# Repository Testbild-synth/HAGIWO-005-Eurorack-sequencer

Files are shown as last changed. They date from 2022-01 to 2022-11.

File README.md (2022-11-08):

# HAGIWO 005 Eurorack Generative Sequencer Module
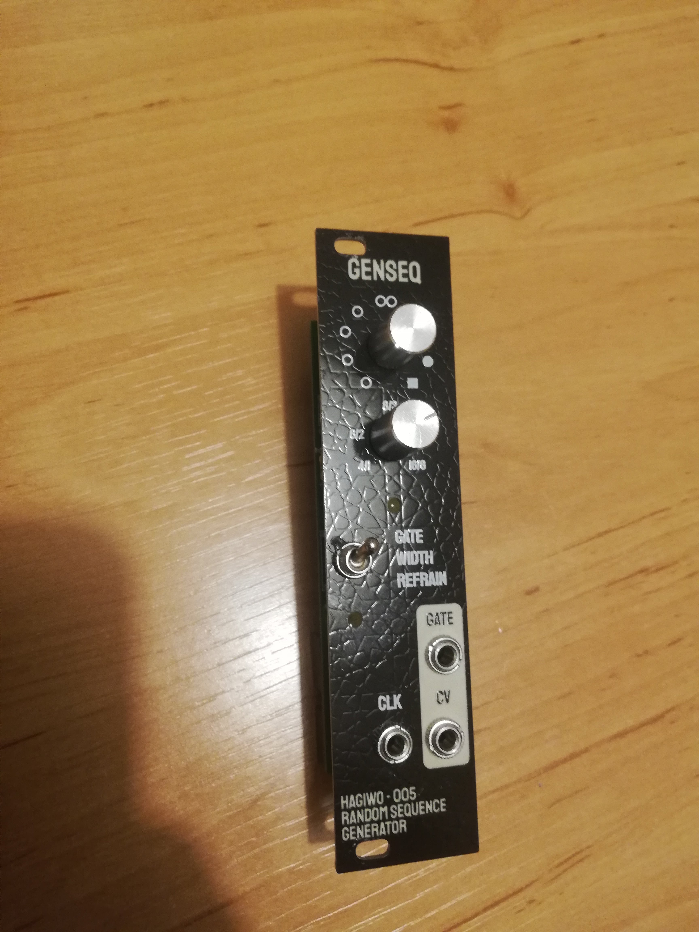
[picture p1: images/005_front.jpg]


Through hole PCB version of the [HAGIWO 005 Generative Sequencer](https://www.youtube.com/watch?v=S4yxVxi9Iak) Eurorack module.
The module is a very simple Arduino-based CV and gate generator that gives random sequences similar to a music things modular turing machine.
Parameters can be set to change different parameters of the sequence.

## Hardware and PCB
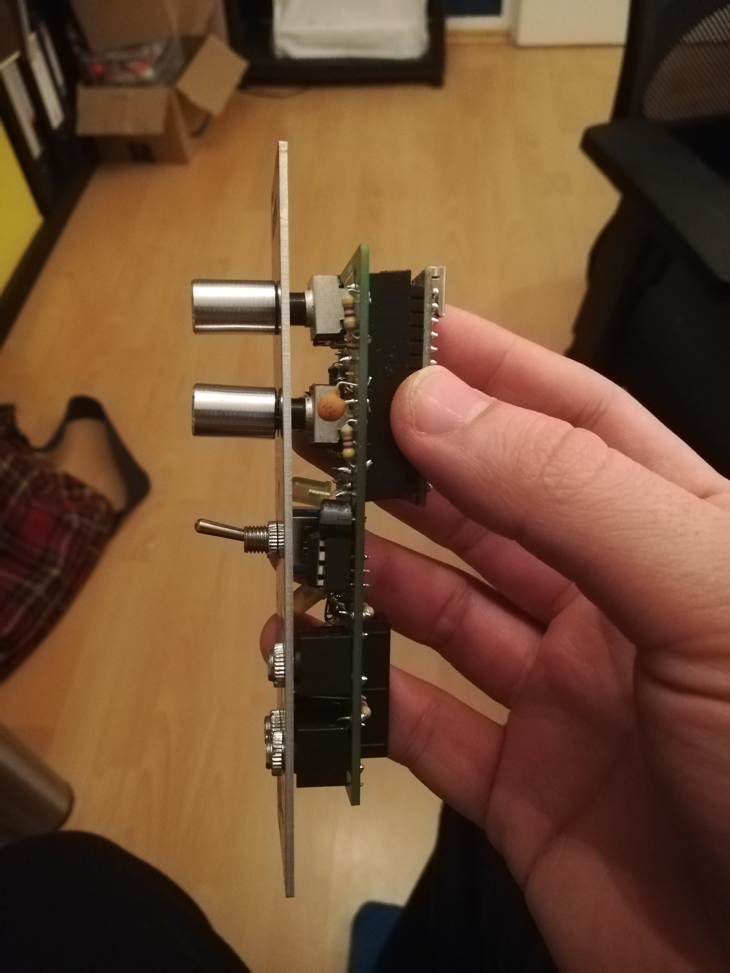
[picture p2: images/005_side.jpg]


You can find the schematic and BOM in the root folder. For the PCBs, the module has one circuit PCB and one panel PCB. You can order them on any common PCB manufacturing service, I used JLCPCB. Standard settings should be fine.

I have uploaded the panel kicad and inkscape files if you want to change fonts etc. (I use the great [svg2shenzen](https://github.com/badgeek/svg2shenzhen) inkscape extension to do my panels.

you should probably make the led resistors (the 330 ohm ones) something higher like 1k, the leds on mine are very bright

As with some of my other modules, this pcb has a selector which allows you to choose if it runs off the 12V or 5V power bus (as some people want 5V but others don't have it in their racks). simply solder the bridge from V_sel to either side or put in a jumper to choose.    

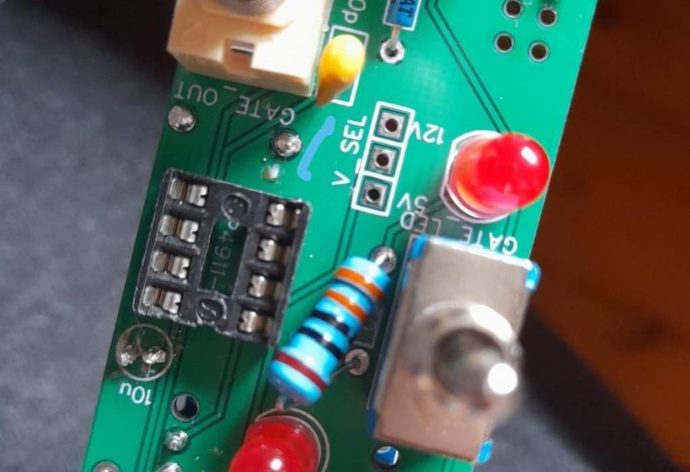
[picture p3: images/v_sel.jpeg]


# TODO:
- code cleanup (it works but could be prettier)

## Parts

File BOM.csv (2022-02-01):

ID | Name | Designator | Type | Quantity
1 | 10u | C1 | Electrolytic capacitor through hole | 1
2 | 220p | C2,C3 | ceramic capacitor through hole | 2
3 | BAT43 | D1,D2 | Schottky diode through hole | 2
6 | CLOCK_IN, GATE_OUT, V_OUT | J3,J4,J11 | Thonkikonn Jack | 3
10 | GATE_LED, OUT_ELD | LED1,LED2 | LED 5mm | 2
12 | 100k | MAIN,SUB | R9k potentiometer | 2
13 | PWR | P1 | Eurorack Power header | 1
14 | 470 | R1,R2,R3,R4,R11 | Resistor through hole | 5
15 | 330 | R5,R6 | Resistor through hole | 2
16 | ARDUINO_NANO | U1 | Arduino nano v3 | 1
17 | MCP4911-EP | U2 | MCP4911 DIP8 DAC | 1
18 | Switch | U3 | MS103 SPDT on/off/on switch | 1

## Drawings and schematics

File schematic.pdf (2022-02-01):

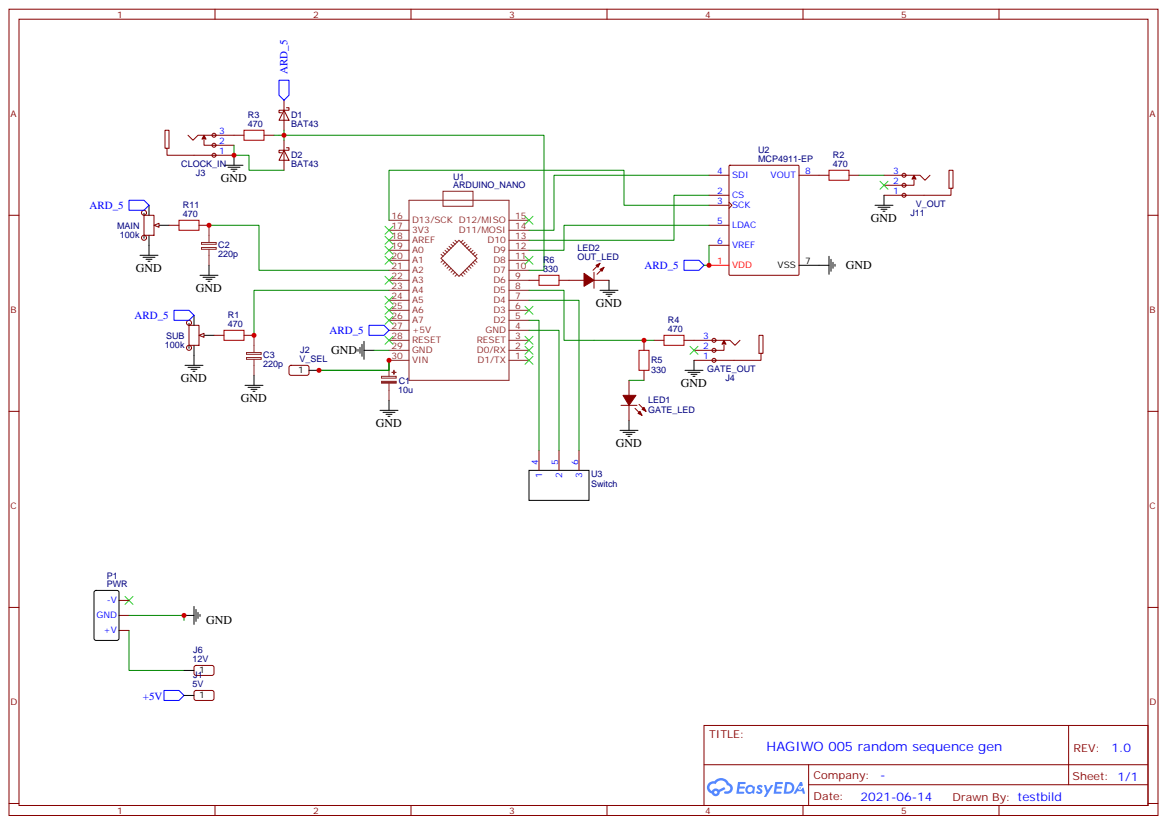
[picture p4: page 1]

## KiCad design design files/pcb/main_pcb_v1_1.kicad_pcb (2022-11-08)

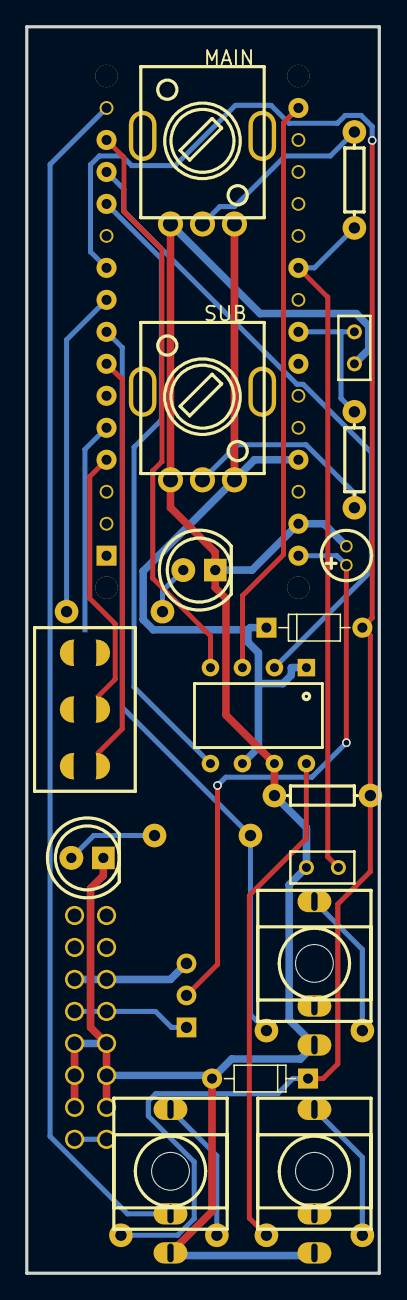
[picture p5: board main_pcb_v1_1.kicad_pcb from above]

Board: 2 copper layers, 28.0 x 99.0 mm, 25 parts (0 on the bottom side), 27 nets.

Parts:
5V: HDR-F-2.54_1x3; HDR-F-2.54_1X3
C1: 10u; CAP-D4.0×F1.5
C2, C3: 220p; RAD-0.1
D1, D2: BAT43; D_DO-35_SOD27_P7.62MM_HORIZONTAL
J3: CLOCK_IN; THONKICONN_1
J4: GATE_OUT; THONKICONN_1
J11: V_OUT; THONKICONN_1
LED1: GATE_LED; LED 5MM
LED2: OUT_LED; LED 5MM
MAIN: 100k; R09-5KΩ
P18: PWR; HDR-IDC-2.54-2X8P
R1, R3, R11: 470; R_AXIAL-0.3
R2, R4: 1k; R_AXIAL-0.3
R5, R6: 2.2k; R_AXIAL-0.3
R7: 100k; R_AXIAL-0.3
SUB: 100k; R09-5KΩ
U1: ARDUINO_NANO; ARDUINO_NANO_WITHMOUNTINGHOLES
U2: MCP4911-EP; DIP8
U3: Switch; SWITCH

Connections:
5V: 5V.3, P18.11, P18.12
12V: 5V.1, P18.9, P18.10
-12V: P18.1, P18.2
ARD_5: D1.1, MAIN.3, SUB.3, U1.27, U2.1, U2.6
GND: C1.2, C2.1, C3.1, D2.2, J3.1, J4.1, J11.1, LED1.2, LED2.2, MAIN.1, P18.3, P18.4, P18.5, P18.6, P18.7, P18.8, R7.2, SUB.1, U1.29, U2.7
J3_3: J3.3, R3.2
J4_3: J4.3, R4.1
MAIN_2: MAIN.2, R11.2
R2_1: J11.3, R2.1
R5_2: LED1.1, R5.2
R6_2: LED2.1, R6.2
SUB_2: R1.2, SUB.2
U1_4: U1.4, U3.5
U1_5: U1.5, U3.4
U1_7: U1.7, U3.6
U1_8: R4.2, R5.1, U1.8
U1_9: R6.1, U1.9
U1_10: D1.2, D2.1, R3.1, R7.1, U1.10
U1_12: U1.12, U2.5
U1_13: U1.13, U2.2
U1_14: U1.14, U2.4
U1_15: J3.2, U1.15
U1_16: U1.16, U2.3
U1_21: C2.2, R11.1, U1.21
U1_23: C3.2, R1.1, U1.23
U1_30: 5V.2, C1.1, U1.30
U2_8: R2.2, U2.8

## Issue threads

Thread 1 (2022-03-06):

fast gpio library read isinputlow?

yentzee, 2022-03-06:
Hi,
first thanks for sharing.
I am modifying the code or at least trying to so that the sequencer can have a reset, ideally that way that as long as a singal is there or abscent the sequencer keeps running and when releasing the button it stops
With the other code I could make it using bool to define the state of the sequencer and connect this with a signal being present or not.
Unfortunately the fast gpio doesnt seem to allow something according to this
FastGPIO::Pin<RESET_PIN>::isInputHigh()
just with the input being low. Do you know if there is such a command?
When changiong high to low it doesnt seem to be a command.
As you can tell I have absolutely no idea how to write code and work my way through by looking at the rest to see how things are done. There might be a better way I don't know. The reason for using your code is that the hagiwocode is pretty laggy when retriggering the sequencer.
Not sure if that makes sense but if it does and you might have an answer I would be very thankful
Cheers,
Jens

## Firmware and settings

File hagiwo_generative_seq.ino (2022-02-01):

#include  <SPI.h>
#include <FastGPIO.h>
//#include <EEPROM.h>

#define SWITCH_PIN1 2
#define SWITCH_PIN2 4
#define GATE_OUT 5
#define LED_OUT 6
#define CLK_PIN 7
#define MAIN_POT_PIN A2
#define SUB_POT_PIN A4

byte stgAgate[2][16] = {
 {0, 0, 0, 0, 0, 0, 0, 0, 0, 0, 0, 0, 0, 0, 0, 0},
 {0, 0, 0, 0, 0, 0, 0, 0, 0, 0, 0, 0, 0, 0, 0, 0}
};

byte stgBgate[2][16] = {
 {0, 0, 0, 0, 0, 0, 0, 0, 0, 0, 0, 0, 0, 0, 0, 0},
 {0, 0, 0, 0, 0, 0, 0, 0, 0, 0, 0, 0, 0, 0, 0, 0}
};

int stgAcv[2][16]  = {
 {0, 0, 0, 0, 0, 0, 0, 0, 0, 0, 0, 0, 0, 0, 0, 0},
 {0, 0, 0, 0, 0, 0, 0, 0, 0, 0, 0, 0, 0, 0, 0, 0}
};

int stgBcv[2][16]  = {
 {0, 0, 0, 0, 0, 0, 0, 0, 0, 0, 0, 0, 0, 0, 0, 0},
 {0, 0, 0, 0, 0, 0, 0, 0, 0, 0, 0, 0, 0, 0, 0, 0}
};

byte i = 0;
byte j = 0;
byte k = 0;

byte gate_set = 1;
byte gate_count = 0;
byte old_gate_count = 0;

byte chance_set = 3;//メインツマミの読み取り値。chanceに数字を渡す
byte chance = 1;//chance_setとlengthから決定。抽選で音が変わる数
byte lottery_stepA = 2;//stgA抽選
byte lottery_stepB = 2;//stgB抽選
byte lottery_done = 2;//抽選を頭一回だけに限定する

const int LDAC = 9;                       // ラッチ動作出力ピン

int sub_knob = 0 ;//サブツマミの読み取りAD値
int old_sub_knob = 0;//SW切り替え直後、切り替え前のAD値を反映させないため、古いADを記憶
byte refrain_set = 1;//リフレインの設定回数。AD値から導出。
byte refrain_count = 0;//リフレインした回数をカウント。指定値に達すると0に戻る。
byte length_set = 4;//レングスの数値
int width_max = 1023;
int width_min = 0;

int main_knob = 0 ;//メインツマミの読み取りAD値
byte repeat_set = 0;//リピートの設定回数。AD値から導出。
byte repeat_count = 0;//リピートした回数をカウント。指定値に達すると0に戻る

byte mode_swA = 0;
byte mode_swB = 0;
byte mode_set = 0; //0=length,1=width,2=refrain
byte old_mode_set = 4;//SW切り替え直後、切り替え前のAD値を反映させないため、SW状態を記憶

void setup() {
 pinMode(LDAC, OUTPUT) ;//DAC通信用
 pinMode(SS, OUTPUT) ;//DAC通信用
 pinMode(CLK_PIN, INPUT); //gate_input
 pinMode(GATE_OUT, OUTPUT); //gate_output
 pinMode(LED_OUT, OUTPUT);//LED_output
 pinMode(SWITCH_PIN1, INPUT_PULLUP);//mode_swA
 pinMode(SWITCH_PIN2, INPUT_PULLUP);//mode_swB
 digitalWrite(LED_OUT,HIGH);
 digitalWrite(GATE_OUT,HIGH);
 delay(500);
 digitalWrite(LED_OUT,LOW);
 digitalWrite(GATE_OUT,LOW);
 delay(500);
 digitalWrite(LED_OUT,HIGH);
 digitalWrite(GATE_OUT,HIGH);
 delay(500);
 digitalWrite(LED_OUT,LOW);
 digitalWrite(GATE_OUT,LOW);
 delay(500);
 
 
 
 //
 //  length_set = EEPROM.read(0);//前回終了時のデータ読み出し
 //  refrain_set = EEPROM.read(1);//前回終了時のデータ読み出し
 //  width_max = EEPROM.read(2);//前回終了時のデータ読み出し
 //  width_min = EEPROM.read(3);//前回終了時のデータ読み出し


 SPI.begin();
 SPI.setBitOrder(MSBFIRST) ;          // ビットオーダー
 SPI.setClockDivider(SPI_CLOCK_DIV4) ;// クロック(CLK)をシステムクロックの1/4で使用(16MHz/4)
 SPI.setDataMode(SPI_MODE0) ;         // クロック極性０(LOW)　クロック位相０
 delay(50);

 for (i = 0; i < 2 ; i = i + 1) {
   for (j = 0; j < 16 ; j = j + 1) {
     stgAgate [i][j] = random(2);
     stgBgate [i][j] = random(2);
     stgAcv [i][j] = random(1024);
     stgBcv [i][j] = random(1024);
   }
 }
}


void loop() {

 //-------------外部入力状態の読み取り-----------------
 gate_set = digitalRead(CLK_PIN);//gate_input状態を読み取り
 main_knob = analogRead(MAIN_POT_PIN);
 sub_knob = analogRead(SUB_POT_PIN);
 mode_swA = digitalRead(SWITCH_PIN1);
 mode_swB = digitalRead(SWITCH_PIN2);
 old_mode_set = mode_set;

 if ( mode_swA == 1 && mode_swB == 0 ) {
   mode_set = 0;//length
 }
 else if ( mode_swA == 1 && mode_swB == 1 ) {
   mode_set = 1;//width
 }
 else if ( mode_swA == 0 && mode_swB == 1 ) {
   mode_set = 2; //refrain
 }

 if (old_mode_set != mode_set ) {
   old_sub_knob = sub_knob;
   //    EEPROM.update(0, length_set); //変更データをEEPROMに書き込み
   //    EEPROM.update(1, refrain_set); //変更データをEEPROMに書き込み
   //    EEPROM.update(2, width_max); //変更データをEEPROMに書き込み
   //    EEPROM.update(3, width_min); //変更データをEEPROMに書き込み
 }

 //-------------refrainの設定----------------------

 if ( mode_set == 2 && abs(old_sub_knob - sub_knob ) > 30) {
   old_sub_knob = 1200;//abs(old_sub_knob - sub_knob ) > 30が絶対に成立するため
   if ( sub_knob < 25 ) {
     refrain_set = 1;//refrainしない
   }
   else if ( sub_knob < 313 && sub_knob >= 26 ) {
     refrain_set = 2;//1回繰り返し
   }

   else if ( sub_knob < 624 && sub_knob >= 314 ) {
     refrain_set = 3;//2回繰り返し
   }

   else if ( sub_knob < 873 && sub_knob >= 625 ) {
     refrain_set = 4;//3回繰り返し
   }

   else if ( sub_knob >= 874 ) {
     refrain_set = 8;//7回繰り返し
   }
 }

 //----------------length設定---------------------

 if ( mode_set == 0 && abs(old_sub_knob - sub_knob ) > 30) {
   old_sub_knob = 1200;//abs(old_sub_knob - sub_knob ) > 30が絶対に成立するため
   if ( sub_knob < 25 ) {
     length_set = 4;
   }
   else if ( sub_knob < 313 && sub_knob >= 26 ) {
     length_set = 6;
   }

   else if ( sub_knob < 624 && sub_knob >= 314 ) {
     length_set = 8;
   }

   else if ( sub_knob < 873 && sub_knob >= 625 ) {
     length_set = 12;
   }

   else if ( sub_knob >= 874 ) {
     length_set = 16;
   }
 }

 //-------------widthの設定----------------------

 if ( mode_set == 1 && abs(old_sub_knob - sub_knob ) > 30) {
   old_sub_knob = 1200;//abs(old_sub_knob - sub_knob ) > 30が絶対に成立するため
   width_max = 612 + sub_knob * 4 / 10;
   width_min = 412 - sub_knob * 4 / 10;
 }


 //-------------repeatの設定----------------------
 if ( main_knob < 5 ) {
   repeat_set = 0;//repeatしない
   chance = 0;
 }
 else if ( main_knob < 111 && main_knob >= 6 ) {
   repeat_set = 0;//repeatしない
   chance = 1;
 }
 else if ( main_knob < 214 && main_knob >= 112 ) {
   repeat_set = 0;//repeatしない
   chance = 2;
 }
 else if ( main_knob < 376 && main_knob >= 215 ) {
   repeat_set = 0;//repeatしない
   if ( length_set == 4 || length_set == 6 ) {
     chance = 3;
   }
   else {
     chance = 4;
   }
 }

 else if ( main_knob < 555 && main_knob >= 377 ) {
   repeat_set = 0;//repeatしない
   chance = length_set;
 }
 else if ( main_knob < 700 && main_knob >= 556 ) {
   repeat_set = 1;//repeatしない
   if ( length_set == 4 || length_set == 6 ) {
     chance = 3;
   }
   else {
     chance = 4;
   }
 }
 else if ( main_knob < 861 && main_knob >= 701 ) {
   repeat_set = 1;//repeatしない
   chance = 2;
 }
 else if ( main_knob < 970 && main_knob >= 862 ) {
   repeat_set = 1;//repeatしない
   chance = 1;
 }
 else if ( main_knob < 1024 && main_knob >= 971 ) {
   repeat_set = 1;//repeatしない
   chance = 0;
 }
 //----------------抽選処理開始---------------------
 if (refrain_count == 0 && gate_count == 1 && lottery_done == 0 && repeat_count == 0 ) {
   lottery();//抽選処理開始
   lottery_done = 1;
 }


 //-----------------stgシーケンス出力-----------------

 switch (repeat_count) {

   case 0:
     switch (gate_set) {

       case 0:                   //gate_inputがLOWのとき
         digitalWrite(GATE_OUT, LOW); //gate_outputをLOWにする
         old_gate_count = gate_count;
         break;


       case 1:                   //gate_inputがHIGHのとき
         if (old_gate_count == gate_count) {
           gate_count ++;

           if ( gate_count > length_set ) {
             gate_count = 1;
             refrain_count ++;

             if (refrain_count >= refrain_set ) {//stgAからstgBへの橋渡し
               repeat_count++;
               refrain_count = 0;
               lottery_done = 0;
             }
           }
           WriteRegister(map(stgAcv[0][gate_count - 1], 0, 1023, width_min, width_max));
           digitalWrite(GATE_OUT, stgAgate[0][gate_count - 1]); //CV出力を出してからゲート出力
           analogWrite(6, stgAcv[0][gate_count] / 4);
           break;
         }
         break;
     }

   case 1:
     if (repeat_set == 0 ) {
       repeat_count = 0;
     }
     else {
       switch (gate_set) {

         case 0:                   //gate_inputがLOWのとき
           digitalWrite(5, LOW); //gate_outputをLOWにする
           old_gate_count = gate_count;
           break;


         case 1:                   //gate_inputがHIGHのとき
           if (old_gate_count == gate_count) {
             gate_count ++;

             if ( gate_count > length_set ) {
               gate_count = 1;
               refrain_count ++;

               if (refrain_count >= refrain_set ) {//stgBからstgAへの橋渡し
                 repeat_count++;
                 refrain_count = 0;
                 if ( repeat_count >= 2 ) {
                   repeat_count = 0;
                   lottery_done = 0;
                 }
               }
             }
             WriteRegister(map(stgBcv[0][gate_count - 1], 0, 1023, width_min, width_max));
             digitalWrite(5, stgBgate[0][gate_count - 1]); //CV出力を出してからゲート出力
             analogWrite(LED_OUT, stgBcv[0][gate_count] / 4);
             break;
           }
           break;
       }
     }

     //開発用
     //      Serial.print( sub_knob);
     //      Serial.print(",");
     //      Serial.print( length_set);
     //      Serial.println("");
 }
}

void lottery() {

 if ( chance != 0 ) {
   for (k = 0; k <= chance ; k = k + 1) {
     lottery_stepA = random(length_set);
     stgAgate[0][lottery_stepA] = 1 - stgAgate[0][lottery_stepA];
     stgAcv[0][lottery_stepA] = random(1024);

     lottery_stepB = random(length_set);
     stgBgate[0][lottery_stepB] = 1 - stgBgate[0][lottery_stepB];
     stgBcv[0][lottery_stepB] = random(1024);
   }
 }
}
void WriteRegister(int dat) {
 digitalWrite(LDAC, HIGH) ;
 digitalWrite(SS, LOW) ;
 SPI.transfer((dat >> 6) | 0x30) ;   // Highバイト(0x30=OUTA/BUFなし/1x/シャットダウンなし)
 SPI.transfer((dat << 2) & 0xff) ;        // Lowバイトの出力
 digitalWrite(SS, HIGH) ;
 digitalWrite(LDAC, LOW) ;     // ラッチ信号を出す

}

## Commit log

2022-02-01 upload arduino code
2022-02-01 added panel pcb files and kicad
    [hagiwo_genseq.kicad_pcb]
2022-02-01 Add files via upload
    added schematic and BOM
    [BOM.csv]
2022-02-03 new folder structure to keep consistent with other repos
    [hagiwo_genseq.kicad_pcb]
2022-02-03 upload kicad and easyeda files
    [main_pcb.kicad_pcb]
2022-11-08 slight fixes and simplifications for main pcb
    [main_pcb.kicad_pcb, main_pcb_v1_1.kicad_pcb]
